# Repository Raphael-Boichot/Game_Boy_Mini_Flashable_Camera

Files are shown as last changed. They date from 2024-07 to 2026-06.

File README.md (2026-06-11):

# The Game Boy Mini Flashable Camera - a fork

**A license free flashable version of the Game Boy Camera, in a small form factor. A fork I've made to render the project doable without external help. All necessary informations are here. I also propose an alternative simpler design requiring less components.**

**The license (rather the absence of it) allows you to do what you want with your mod: selling it, offering service for doing the mod, modifying it starting from the schematic, it's up to you.**

**The design was made from scratch and people involved have no hidden conflict of interest with any other similar project. We are not here for money or fame, this project is just a gift to the Game Boy modding community.**

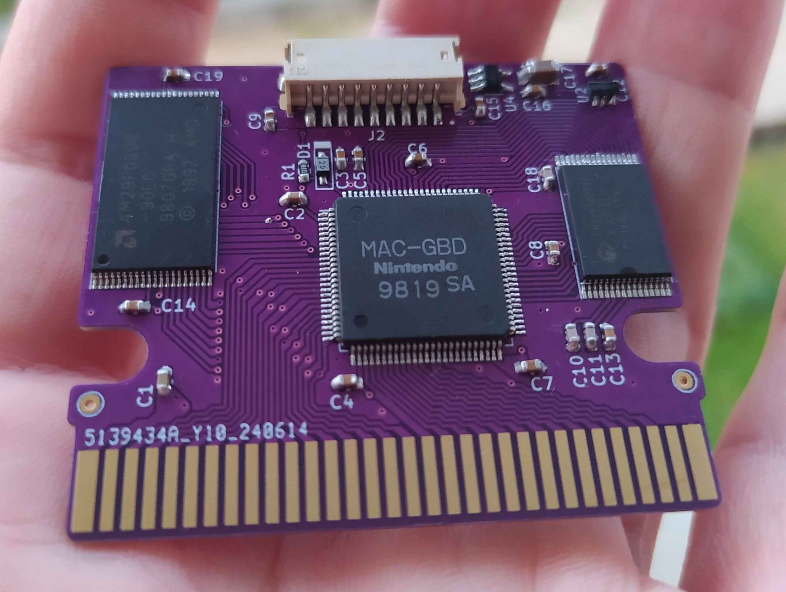
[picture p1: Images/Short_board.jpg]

**Isn't this gorgeous in purple ?** (Credit: Raphaël BOICHOT)

The current release has been produced, assembled, tested and bullet proofed. The board is compatible with any regular camera ROM (Game Boy Camera, Pocket Camera, Hello Kitty, Zelda special edition and [Debagame tester](https://tcrf.net/Proto:Game_Boy_Camera)) and homebrews like [Photo!](https://github.com/untoxa/gb-photo) or [2bit PXLR Studio](https://github.com/HerrZatacke/2bit-pxlr-studio). It is recommended to flash this board with a [GBxCart](https://www.gbxcart.com/) and [FlashGBX](https://github.com/lesserkuma/FlashGBX) as support is guaranteed. FlashGBX automatically recognizes it without doing anything. Other flashing devices (GB Operator, Cyclones and other Chinese oddities) were not tested, try them by yourself. Some considerations made in this repository are just related to me being a cheap modder living in Europe and everything else being sold from US/China, so adapt the reading level to your own localization / wealth.

***Note from April 2026: I do not (and won't) keep track of the main fork and its more or less documented updates as the version forked here (1.4) perfectly does the job. The 1.5 (dismissed since) was just the 1.4 with a pad to skip the signal inverter and the current 2.0 is a double bank PCB with added functions which does not have the beautiful simplicity of the 1.4.***

## Why this fork ? Isn't the main branch enough ?

In short: no. Let me explain the story first, it's interesting.

The main branch has been published by 2BitWizard with a minimalistic readme during the summer 2023. The author kindly shipped to me some pre-release boards for feedback (as well as to a bunch of other modders). 2BitWizard and I were both quite active members on some retro stuff related Discord. Unfortunately, 10 months passed before I found time/motivation to dive seriously into the project (I have no excuses, even though I've spent the year dealing with shit). Meanwhile, I lost any means to contact the author as well as the manual to assemble the pre-release boards (which were different enough from the current project to be lost in translation) after leaving progressively all social media for various good reasons.

But I still owed 2BitWizard a feedback. Because yes, I'm an old-fashioned guy with principles.

To my big surprise, the main branch stayed nearly inactive after the initial commits. Out of curiosity, I've decided to restart the mod from zero, alone with my workbench, putting aside my pre-release boards that I was unable to populate anymore. I wanted to confirm that it was possible to make the project with the only informations, gerbers and schematics provided in the main repository. I found inconsistencies. I had to seek for external help and needed cross validation (see the acknowledgements). I had to fix important things (confirmed by the original author since).

So.

I've decided to make my own fork. I like this project.

## What has been changed compared to the main branch ?

- Inconsistencies between BOM and schematic have been fixed, BOM is simplified;
- All 22 pF caps have been replaced with 39 pF to permanently fix [image artifacts](/Images/Artifacts_with_22pf_C10.png) linked to FRAM. The initial author also shifted to a higher value (33 pF) after observing the same artifacts;
- The project now contains all necessary information to be completed without having to cross-check datasheets and schematics and make educated guesses;
- An [alternative design](/Alternative_design) with less components and using the same PCB is also proposed.

## Minimal hardware/skill required in addition to all the BOM before starting anything

- A multimeter with at least a beeping continuity mode for troubleshooting;
- A 60W soldering iron with a fine tip and a real temperature control. Cheap pencil shape soldering irons are **NOT** an option to consider unless you want to kill yourself;
- A hot air gun (ideally a reflow station) or a heating plate to desolder the MAC-GBD;
- Good quality solder wire/flux or solder paste and solder wick;
- Isopropanol in large quantities to clean all the flux mess;
- A magnifying system like an USB microscope or binocular magnifiers;
- A GBxCart flasher and FlashGBX software. Other flashers may or may not work;
- Some kapton tape (or any whatever branded polyimide tape) to cover the PCB gold fingers during soldering;
- Fine tweezers to handle the tiny components (and experience the joy of capacitor tombstoning);
- 3 hours of free time with your preferred music in background and no kids whining around;
- A good skill in soldering because **this is not a beginner project**. It can really end as a mess if you don't know what you are doing. Keep in mind that the mod is not intended to be easily reversible.

## What to fit it with

The GB mini flashable camera comes in two PCB versions that fit any kind of cool existing shells. It is meant to be as versatile as possible. **The long PCB can be turned into a short PCB by simply breaking the PCB neck so I recommend ordering only the long one as it lets you more shell options.**

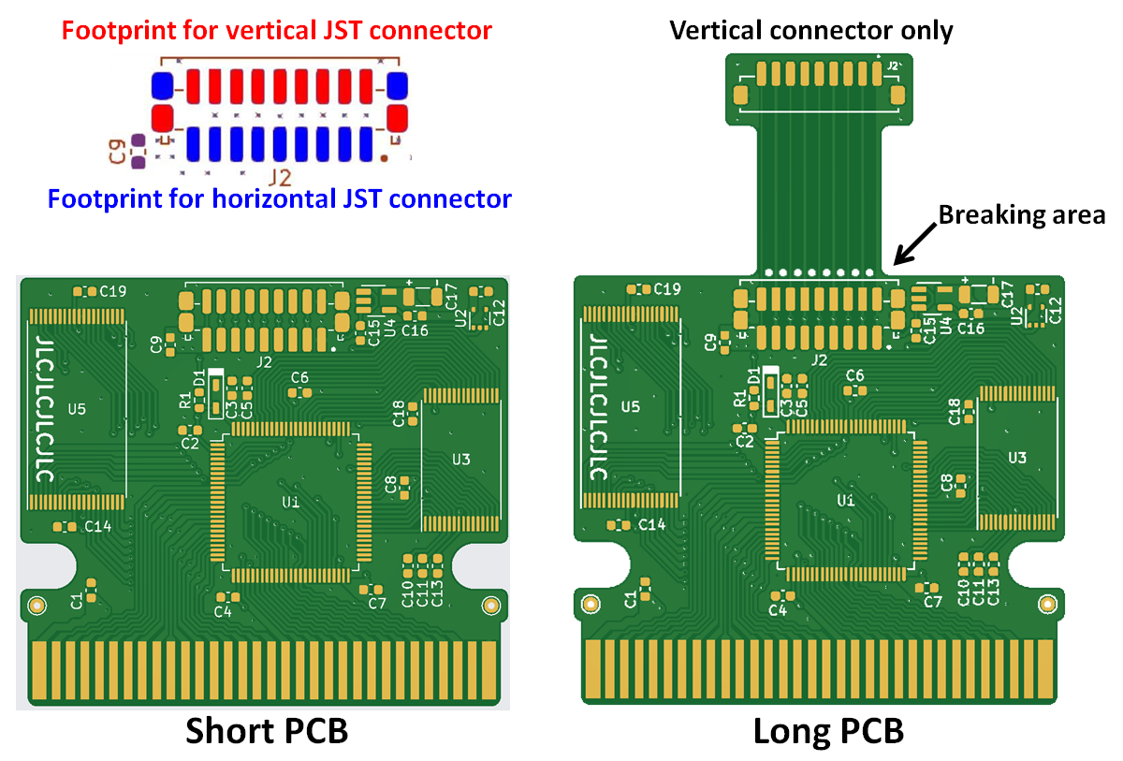
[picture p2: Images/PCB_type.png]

(Credit: Raphaël BOICHOT)

The GB mini flashable camera in short version fits perfectly with the [Camera+ Mini shell](https://ko-fi.com/s/a4d7bd649a). With this shell, you can reuse the regular camera sensor ribbon. **With the short PCB, use an horizontal JST connector as clearance is very low.**

## Showcase with the short PCB in a Camera+ Mini shell

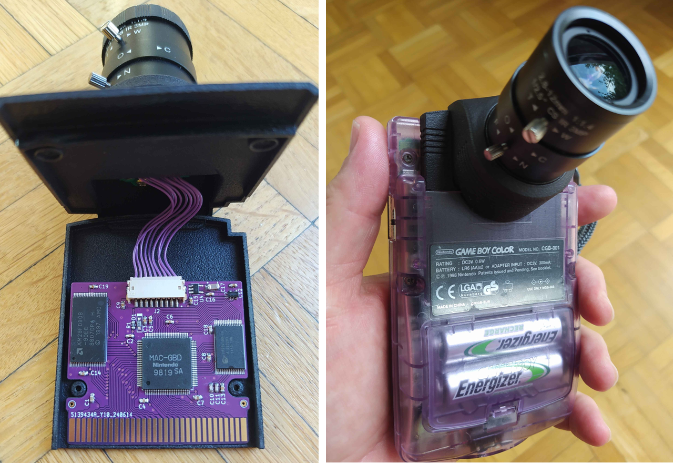
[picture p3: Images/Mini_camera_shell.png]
game boy camera flashable

(Credit: Raphaël BOICHOT)

The long PCB version has a "neck" that allows mounting it in a regular Game Boy Camera or a [Game Boy Camera+ shell](https://ko-fi.com/s/9457d1cc6e) with the regular sensor ribbon as well. **The long neck must be populated with a vertical JST connector only.**

## Showcase with the long PCB in a regular (but fancy) camera shell

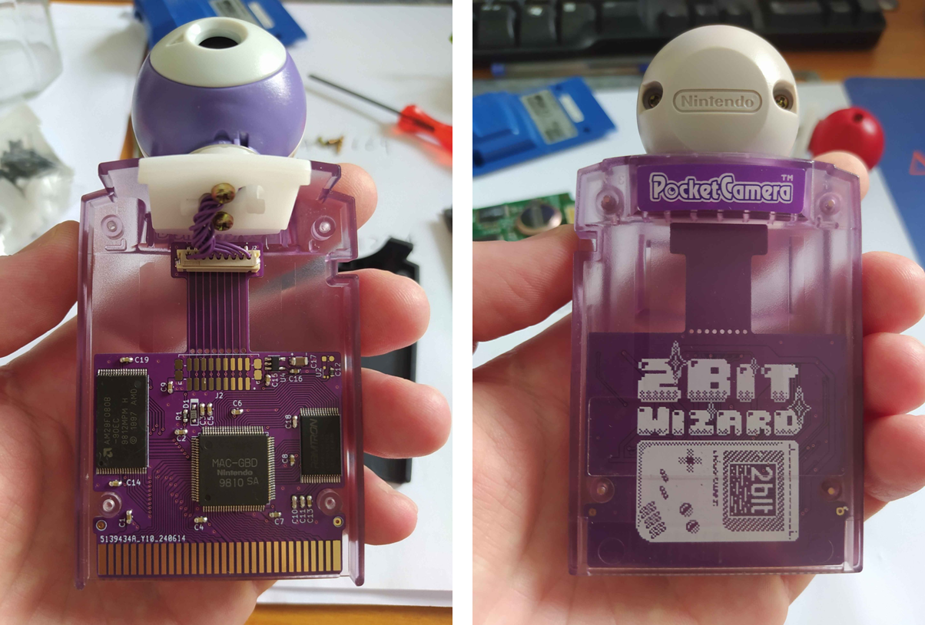
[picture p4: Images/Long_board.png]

Atomic purple case with purple PCB, what could go wrong ? (note the missing signal inverter on purpose, [this is why](/Alternative_design)). Credit: Raphaël BOICHOT.

In case you want to mount the **short PCB** in a regular camera shell (why not after all), you will need a **longer ribbon cable**, and that's where the pain begins. 
**Aliexpress JST cables are much too thick and stiff for that task** (plus they are just crap, do not buy them) and you must order a genuine JST cable. The only known supplier for genuine cables is Digikey (with prohibitive shipping fees to Europe). Choose a [type B cable "socket to socket" ](https://www.digikey.fr/en/products/base-product/jst-sales-america-inc/455/A09ZR09Z/588181). The regular camera cable is [2 inches long](https://www.digikey.fr/en/products/detail/jst-sales-america-inc/A09ZR09ZR28H51B/6708551), so take at least a [4 inches one](https://www.digikey.fr/en/products/detail/jst-sales-america-inc/A09ZR09ZR28H102B/9972202). Digikey ribbon cables are just a bit stiffer than the genuine cables but they can sustain the same amount of bending/torsion without losing connection, in brief they are damn good quality. Fun fact: the JST male connectors from Aliexpress, in the other hand, are just perfectly OK.

Please follow the [building instructions from the original author](/Building_guides/build.pdf) (also given in next section) for PCB ordering options. Use [JLCPCB](https://passport.jlcpcb.com/) for ordering if you live in Europe. They offer VAT compliant services for European customers and very cheap shipping options. I typically got 5 boards ENIG finish shipped to France for 23€ in 2024.

**IMPORTANT note:** you can harvest the voltage regulator from **some versions** of the Game Boy Camera. They are populated either by the U4 or U5 regulator. The current board is designed to work with either the regulator linked in the BOM or the U5 regulator harvested from the original camera cart. **U4 from the original board will not work.** If you're using a new 3V0 regulator from the BOM list, the **C16 capacitor will not be necessary.** Unlike the original 3V0 regulator, the pin connected to this capacitor is not connected on the new 3V0 regulator. **I recommend anyway buying the regulator indicated in the BOM to start from fresh.**

## Component location and orientation on PCB

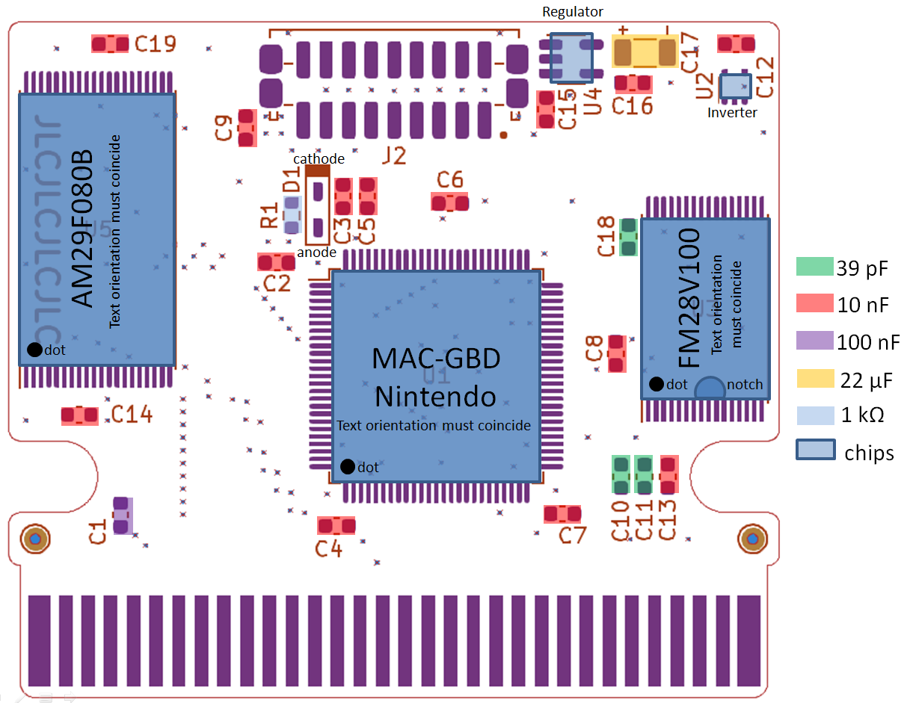
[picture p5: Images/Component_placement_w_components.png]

(Credit: Raphaël BOICHOT)

It's not an interactive BOM but it will do the job. If you are colorblind, please refer to the next table which is the same. **No component other than the MAC-GBD need to be harvested from the original camera PCB.** You can also take a look to my proposal of [alternative design using less components](/Alternative_design).

## Component list (BOM)

|Silkscreen |Value |# |Footprint |Exact reference |Aliexpress link |
|---|---|---|---|---|---|
|C1	|100nF	|1	|0603 |Capacitor Ceramic (X7R)	|[100 nf - 0603](https://www.aliexpress.com/item/1005005690927737.html)|
|C2 to C9, C12 to C16, C19	|10nF	|14	|0603 |	Capacitor Ceramic (X7R)|[10 nf - 0603](https://www.aliexpress.com/item/1005005690927737.html)|
|C10, C11, C18	|39pF	|3	|0603 |Capacitor Ceramic (X7R)|[39 pf - 0603](https://www.aliexpress.com/item/1005005690927737.html)|
|C17	|22µF	|1	|1206 |Capacitor Tantalum (≤10%)	|[22 µf, 16V X7R - 1206](https://www.aliexpress.com/item/1005006022131059.html)|
|D1	|N/A	|1	|SOD-123 |BAT54W-HG3-18 Schottky diode|[BAT54W - SOD-123](https://www.aliexpress.com/item/1005007021313163.html)|
|J2	|N/A	|1	|N/A	|JST ZH1.5mm (9 pins)	Camera Connector (male, horizontal or vertical)|[9 pins JST connectors](https://www.aliexpress.com/item/1005006028155508.html)|
|R1	|1kΩ	|1	|0603 |Resistor	|[1kOhm - 0603](https://www.aliexpress.com/item/1005005677654015.html)|
|U1	|N/A	|1	|TQFP-100 |MAC-GBD gamecart mapper chip|Harvest from cart|
|U2	|N/A	|1	|SC-88A-5 |M74VHC1GU04DFT1G Signal inverter|[M74VHC1GU04DFT1G](https://www.aliexpress.com/item/1005006984696269.html) - see notes before ordering|
|U3	|N/A	|1	|TSOP-I-32 |FM28V100-TG FRAM|[FM28V100-TG - TSOP-32](https://www.aliexpress.com/item/1005007221226758.html)|
|U4	|N/A	|1	|SOT-23-5	|NCP718ASN300T1G 3V0 voltage regulator|[NCP718ASN300T1G - SOT-23-5](https://www.aliexpress.com/item/1005005585077756.html)|
|U5	|N/A	|1	|TSOP-I-40 |AM29F080B	Flash memory|[AM29F080B - TSOP-40](https://www.aliexpress.com/item/1005007324498768.html)|

The PCB was designed on purpose with "big" surface mount components only. Anything smaller than the 0603 footprint would be just sadistic for this kind of leisure project.
You can report dead Aliexpress links in the **issues**, I will update them ASAP. I did not try to optimize shipping fees here, there is maybe a cheaper combination of sellers.

## Schematic

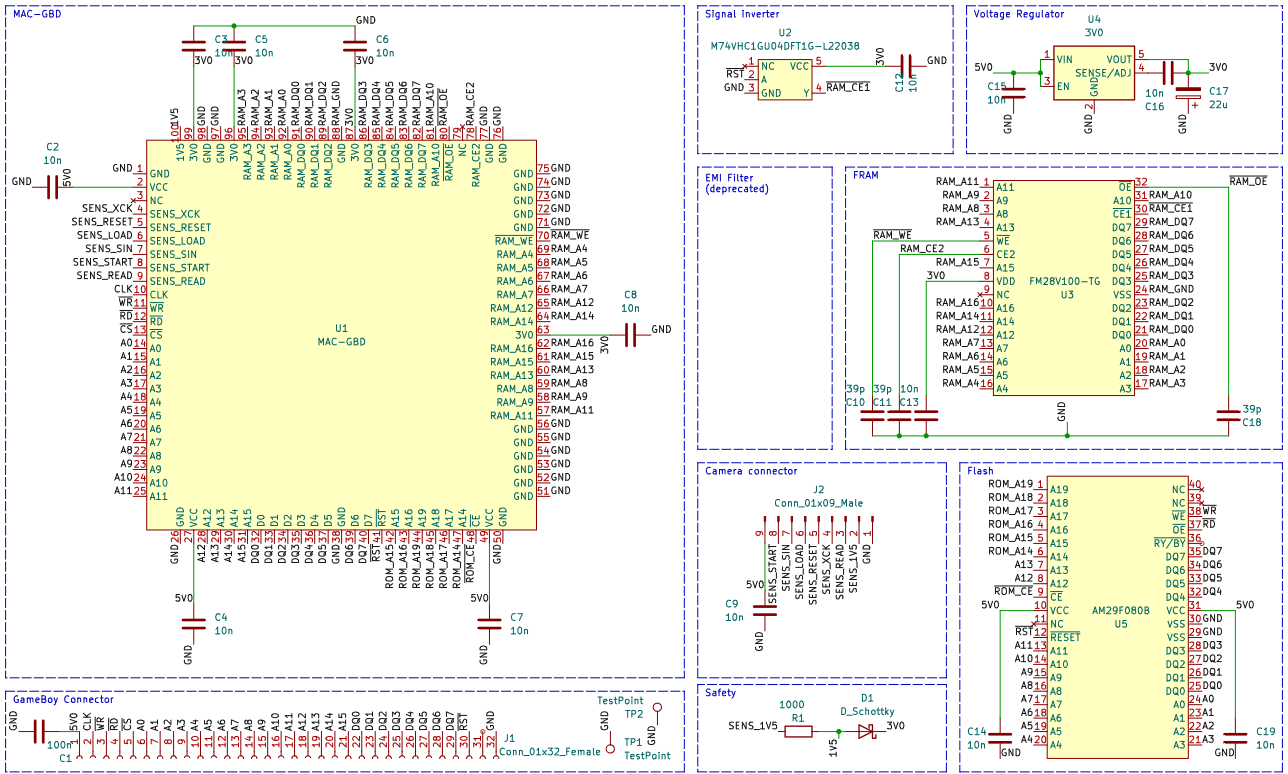
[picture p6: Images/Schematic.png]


## Overview of JLCPCB ordering options

Base Material **FR-4**, Layers **2**, Dimensions **Auto-filled**, PCB Qty **As desired**, Product type **Industrial/Consumer electronics**, Different Design **1**, Delivery format **Single PCB**,  PCB thickness **0.8**, PCB Color **As desired**, Silkscreen **As desired**, Surface Finish **ENIG**, Outer Copper weight **1 oz**, Via Covering **Tented**, Board Outline Tolerance **±0.2mm(Regular)**, Confirm Production file **No**, Remove Order Number **Specify a location**, Flying Probe Test **Fully Test**, Gold Fingers **Yes**, 30°finger chamfered **No**, Castellated Holes **No**.

## Notes (please read completely before attempting the project)

- The M74VHC1GU04DFT1G signal inverter, in particular in SC-88A package, can be tricky to source (only remaining seller is Mouser), so a solution is to switch to a MC74VHC1GU04DF1G (solution proposed by Digikey) or to another close package (like the SC−74A, only one you will receive from Aliexpress, whatever claim the sellers). **The SC-88A package is equivalent to SOT-353 or SC-70-5 if you search for old new stocks. The package SC−74A, slightly bigger, can be used too in case of no other choice, it barely fits, but fits anyway, on the SC-88A footprint (same pinout).** If it is not soldered correctly (cold joint), you will get a white image, easy to debug so. Do not hesitate to carefully bend the pins to ease the matching.
- The schematic only is **open source** and can be edited with Kicad. The author chose to not disclose the PCB layout whatever the reason. You have to create your own if you want to change something.
- C10, C11 and C18 capacity has been increased compared to the original design to remove any graphical glitch due to FRAM timing inconsistencies. It is now perfectly working with the cap values proposed in this fork (39 pf versus 22 pf originally).
- The AM29F080B, as most of 5 volts flash chips, is discontinued since many years but easy to find on Aliexpress for cheap (batches are mainly recycled chips). It can be fun to dump the content before flashing it to see what the chip usage was before its recycling (it is said that some old phone flash chips can be funny to dump).
- Some late versions of the FM28V100 FRAM by Cypress Semiconductors come without a dot to indicate pin 1 but only a side notch. The side notch also indicates the row where pin 1 is located, so it must be soldered with notch pointing down (same as the dot if present).
- Recycled FRAM from Aliexpress are 10x cheaper than new ones sold on Mouser or Digikey. The FM28V100 is known for being very reliable in general. I never got any defective FRAM chip of this capacity from Aliexpress. Seeing the price, it's a no-brainer for me: recycled chips only. Sidenote: RAMTRON was acquired by Cypress semiconductors in 2014, both are the same fabless manufacturer now. There is no rational reason to prefer RAMTRON over Cypress branded chips. RAMTRON branded chips are just older stocks.
- The low voltage Schottky diode proposed here is generic and any equivalent one will do the job (there are several). The original camera used a Panasonic MA784 with marking **2D** (discontinued), among other undocumented variations, you can take inspiration from its datasheet. The RB510VM-30 is a possible alternative for example. It must have the **lowest possible forward voltage drop and the highest possible reverse voltage**. Its purpose is to protect the 0-3.3V MAC-GBD internal analog to digital converter from any overvoltage coming from sensor image signal, so the anode is connected to VOUT (1V5 in the schematic) and the cathode to 3V0. It triggers at around 3.18V on the anode. Whatever the diode used, it has a specific mark on the cathode (see corresponding datasheet, can be a white line on black background or the inverse). Compared to the main branch, I've removed the BAT 63-02V as possible alternative to the Schottky diode due to its very low reverse voltage (3V only versus 30V for the original diode).
- Most parts can be found on Aliexpress, Mouser and Digikey except for the ribbon cable (Digikey only). I overall recommend ordering on **Aliexpress or Mouser** if you are in Europe, after a very deceptive customer experience with Digikey, to say the least.
- You can easily desolder the MAC-GBD by using a hot air gun (set at about 400°C) on the **back side** of the original board until the chip falls by itself or after a gentle shaking (add flux to ease the melting). This is by far the most simple way I've found (I do not own a heating plate). I do not recommend using low temp solder or other bismuth containing crap. No need. The author of the original project recommends using a heating plate set at 250°C. In any case, work fast to minimize at most heat budget on the chip.
- Lead free solder in wire can be very crap depending on the alloy and could be a pain to melt due to high melting point, in particular without flux core. Either use old good lead/tin alloy with flux core (and a ton of flux anyway) if you can find some, or quality lead free solder paste. And always remind the rule of thumb when using flux: "the bigger the blob, the better the job".
- The ferrite beads filters have been removed from the definitive PCB even if they are still mentioned in the pdf description of the project.
- The schematic is **clear and comprehensive enough to troubleshoot any issue** by yourself with a multimeter in continuity mode. Easy check after soldering: the caps must **never** be shorted, two adjacent pins of the FRAM and flash memory must never be shorted (beware, it's not as simple on the MAC-GBD side). After that, any remaining issue is a just a matter of flow and reflow due to some dry solder joint.
- It's **very recommended** to use a magnifying system (USB microscope or binocular magnifier). Soldering with bare eyes is possible if you are lucky enough to get the device working first try but any issue will be impossible to troubleshoot.
- The PCB ENIG finish can be hard to "wet" with solder depending on the flux used. I used a generic "no clean" flux in a syringe, which was OK in my case (good flux wetting, easy to "no clean" with isopropanol, not greasy and no headache after long soldering sessions contrary to some other el cheapo Aliexpress fluxes in metal containers I used to spread before). AMTECH seems to be a good brand if you need to choose one.
- Of course, cover the cartridge connector completely with kapton tape during soldering to avoid any solder splats on them. They are basically **impossible** to remove after, so better avoid them.
- I also recommend to clean with flux/solder wick/isopropanol and unbend very thoroughly under microscope the pins of the MAC-GBD or any recycled chip **before** soldering them to the PCB. A solder bridge due to a metal particle between/below pins (like a tiny ripped pad, own experience...) is very annoying to remove (you basically have to remove the whole chip to get rid of it and clean all the pins, so better doing it before becoming crazy).
- I've soldered the components in this order: chips (to have clearance), caps/diode/resistor, regulator/inverter, and then the connector. I've cleaned board between each step with isopropanol to get a clear view of the work and check for dry solder joints and obvious shorts.
- First connection to FlashGBX will always report a bad/unknown mapper/ROM but as soon as you try to flash a ROM everything will go fine. I recommend flashing a regular ROM first (which fills the whole 1MB flash chip) and fill the whole memory with different images for testing. If after reboot all your images are still there without artifacts, you're good to go with your new device !
- As the populated PCB is full "solid state", it can be cleaned by directly soaking it in isopropanol / hot soapy water and using a toothbrush, the caps risk nothing.
- I learnt soldering surface mount stuff years ago by just watching Youtube and praticing, so it's not rocket science either. Hardware is the key: choose powerful enough soldering iron with temperature control (typically an iron with power transformer and head in two different pieces, not single cord pen form factor with a knob, they are all crap), good solder alloy, good soldering wick, flux in a syringe, accurate magnifying device. Best is of course to start practicing soldering/desoldering with simplier projects first.
- I guess that the PCB can be fully assembled at once with solder paste and a heating plate/reflow station. I just have no experience doing this and you probably would have to prepare a stencil for that.

## Example of pictures taken with the Camera+ Mini shell and a 2.8-12 mm CS lens

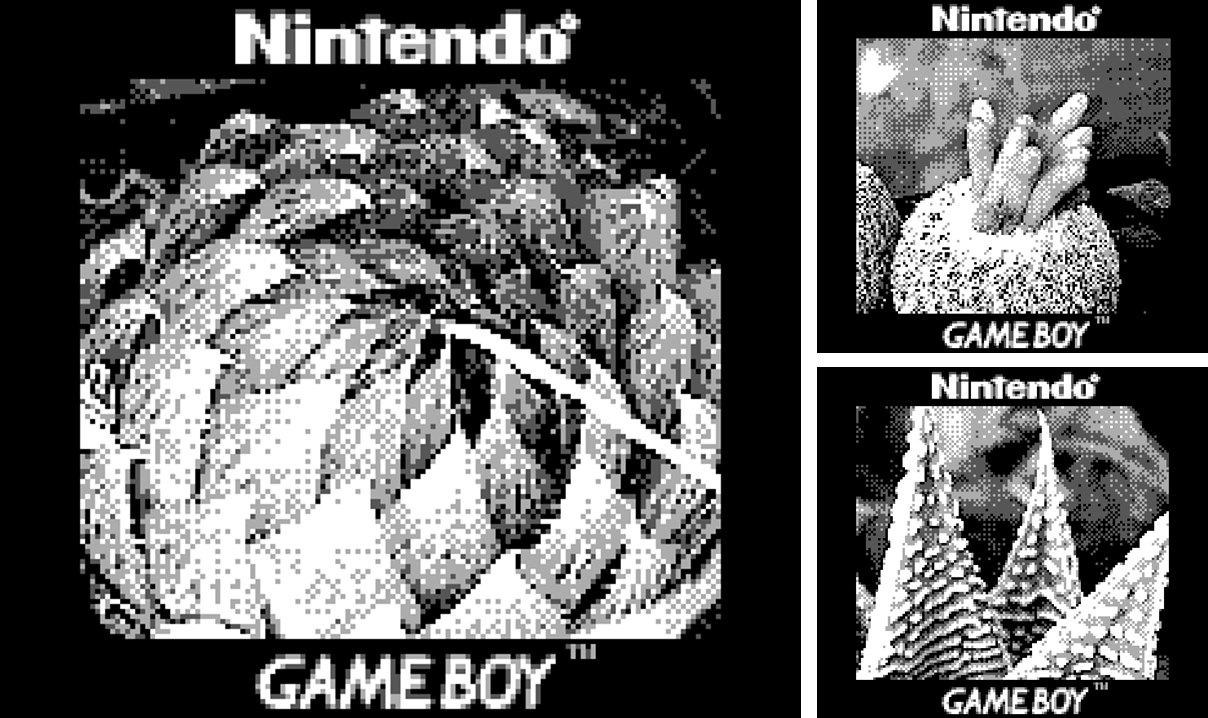
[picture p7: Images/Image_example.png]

(Credit: Raphaël BOICHOT)

## Notes for ordering the Camera+ Mini shell

- I've ordered [this version of the Camera+ Mini shell](/Shell) at JLCPCB with the following option: 3D Technology: MJF(Nylon) Material: PA12-HP Nylon Colors: Black Surface Finish: Dyeing-Dyed Black. It came very nice and sturdy like this. The price in 2024, shipped to France, was 17€ for the full set of pieces.
- The C/CS mount I bought was way to large to enter the front hole so I had to file its external diameter until it fit with a moderate force. At this step, you can adjust the C/CS mount deepness until your lens can easily focus to infinity before glueing it definitely by the inside. The mod is very well made so even with the C/CS ring completely pressed inside the hole, it must be OK.
- CS lenses are very cheap and good quality on Aliexpress. My go-to lens is a [2.8-12 mm](https://a.aliexpress.com/_EQWPAAN) which covers 99% of my needs. The 5-50 mm is not bad either. To guide your choice, the sensor crop factor is about 10 (5 mm with Game Boy Camera sensor is equivalent to 50 mm with full frame sensor). The original camera plastic lens is about 35 mm equivalent (3.5 mm with the sensor) to give a reference.
- The mod does reuse only screws from the genuine camera shell, which is clever ! You just need some 5 minutes epoxy for gluing the C/CS mount and nothing else.
- The mod is **fully reversible.**
- If you hesitate between the Camera+ and the Camera+ Mini shell, take the Camera+ Mini. It holds very firmly in place with heavy lens mods compared to the Camera+ which center of gravity is a little bit too high for my own taste.

## Notes while troubleshooting / trying new options

- I've received the signal inverter in the wrong package from two different Aliexpress sellers (package SC−74A, it was referenced as SC-88A but it was not). It barely fits and was tricky to solder correctly on the traces but it works. As long as the chip marking begins by V6, chip/pinout is the same. Lack of connection between FRAM and the signal inverter will result in a permanent white image, easy to recognize. I've tried to get rid of it by "shorting" RAM_CE1 to GND with a 1kOhms resistor (it has just the required length and makes a solid bridge, right pads on U2 foorprint), it of course also works.
- I've used an old new stock Panasonic MA784 Schottky diode because I bought a bunch of them years ago to confirm that the Game Boy Camera uses exactly the same.
- Using a 22 pf capacitor for C10 as recommended in the original repo led to image glitches on my side (I must point out that I did not specifically order X7R caps but was working at "room temperature" with unbranded caps). Typical image glitches due to weak caps with FRAM are missing brightness levels, more or less obvious (an [example can be seen here](/Images/Artifacts_with_22pf_C10.png)). As I knew that this very particular cap was crucial for FRAM stability (because I'm not a six-week-old rabbit either), I've tried doubling or dividing the value by two (and swapping the FRAM chip, I thought it was maybe the culprit but in fact not). Dividing the capacitance by two made glitches worse (image turned to 1 BPP). Doubling to 44 pf with two 22 pf in parallel completely fixes the graphical glitches. So I then tried a 39 pf cap to be closer from initial value and it was OK. As C11 and C18 are less critical than C10 and to avoid ordering too many different cap references, they were also increased to 39 pf. These values are validated as perfectly working on my side (on a 4-40°C temperature range at least). I think that 22 pf was a very minimal value with no safety/tolerance on design margin.
- I've soldered C16 in place even if it is not required as I used a new voltage regulator (I'm quite superstitious when dealing with electronics and there is never too much caps).

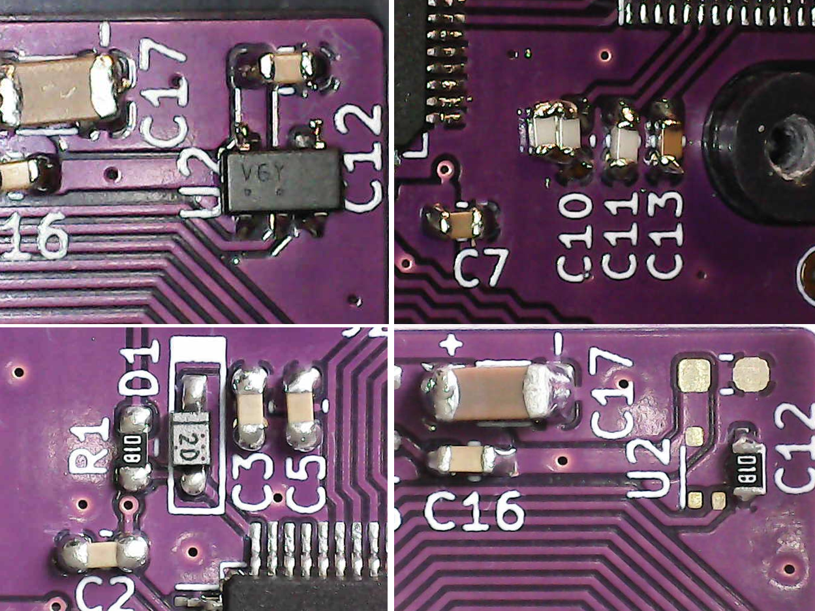
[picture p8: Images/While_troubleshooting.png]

(Credit: Raphaël BOICHOT)

## Some basic glitches easy to spot

Some cold solder joints between the MAC-GBD and the SRAM allow the camera to boot and create very predictible glitches. Just look at the image and you know where to reflow !

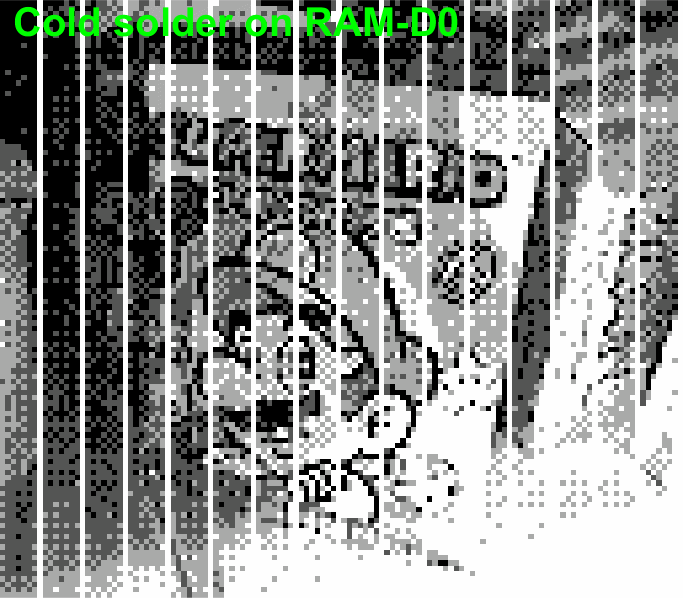
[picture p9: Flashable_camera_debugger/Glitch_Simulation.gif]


## Acknowledgements

- [Andreas Hahn](https://github.com/HerrZatacke) and [Mraulio](https://github.com/Mraulio) for helping me to complete this fork by confirming me some educated guesses I had to do and giving me some informations only accessible from the deep web.
- [2BitWizard](https://github.com/2BitWizard), original author, for bringing the project to fruition, sending me prototype boards and giving feedback on my feedbacks (Well, it wasn't exactly a thank-you either). 

- [2BitToy](https://ko-fi.com/2bittoy/) for his great/neat camera mods. Don't forget [donation](https://ko-fi.com/s/a4d7bd649a) if you appreciate this mod.

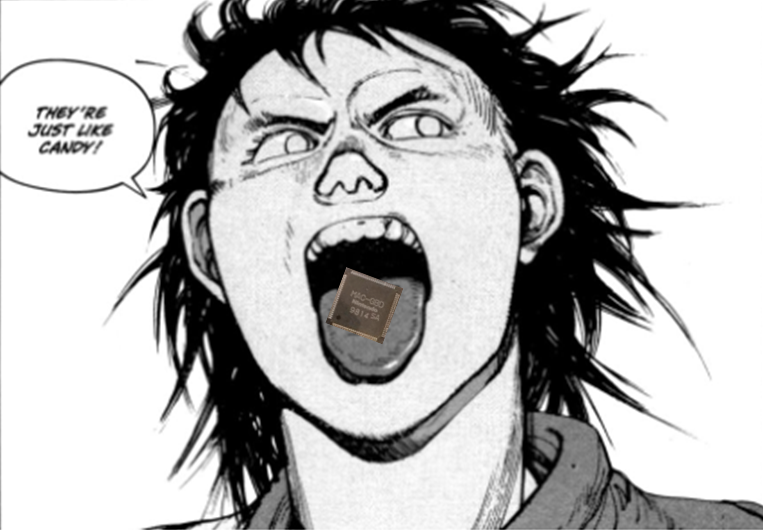
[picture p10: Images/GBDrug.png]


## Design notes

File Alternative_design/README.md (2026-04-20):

# Alternative design proposal for the 2BitWizard project

## 1. Get rid of the signal inverter

RAM_CE1 can be connected to ground directly, without the signal inverter. You can use a 1kOhms resistor to make the bridge as it is exactly the good lenght, just be carefull to not short RST and GND in the process. You can get rid of C12 in this case (see [an example here](/Images/While_troubleshooting.png)). My understanding is that the RESET signal is intended to be pulled down by the [battery backup management system](https://github.com/MouseBiteLabs/Game-Boy-MBC3-Cartridge/tree/main/Technical) (not used here because FRAM), to halt **both CPU operation AND writing to SRAM** when voltage is unstable while the Game Boy is powered down. But as it is pulled high on the Game Boy CPU side by default, the signal inverter pulls it down and always allows writing to the FRAM when Game Boy is ON. What a wire to ground does perfectly too. I can find at least as many arguments pro or against grounding RAM_CE1 or using the inverter.

**Possible placements for a 1kOhms resistor (or jumper wire, or 0 Ohm) to ground RAM_CE1 pin**
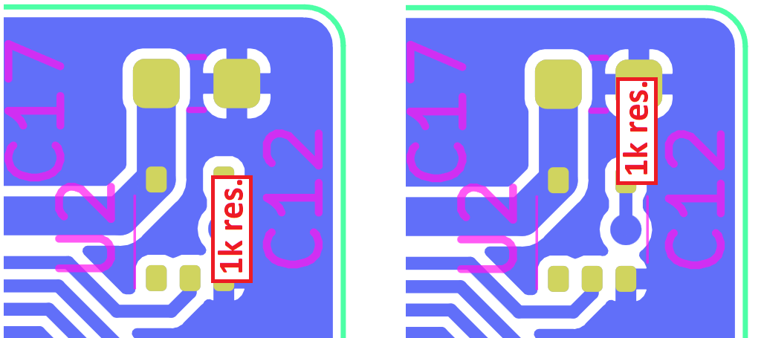
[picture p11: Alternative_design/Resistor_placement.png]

(Credit: Raphaël BOICHOT)

The author has since released a ~~1.5~~ 2.0 version (see [original repo](https://github.com/2BitWizard/GB_Mini_Camera)) that just adds a jumper (JP1) to do this cleanly. I however did not test this release.

## 2. Use only 100 nf caps on the voltage lines

Use only 100 nf capacitors instead of 10 nf capacitors on voltage lines to reduce the number of references to buy. 100 nf or more is the default cap value for many cart mods on voltage lines, so do not hesitate as 10 pf caps are of no use for other related mods. 

**Alternative capacitor placement on PCB**
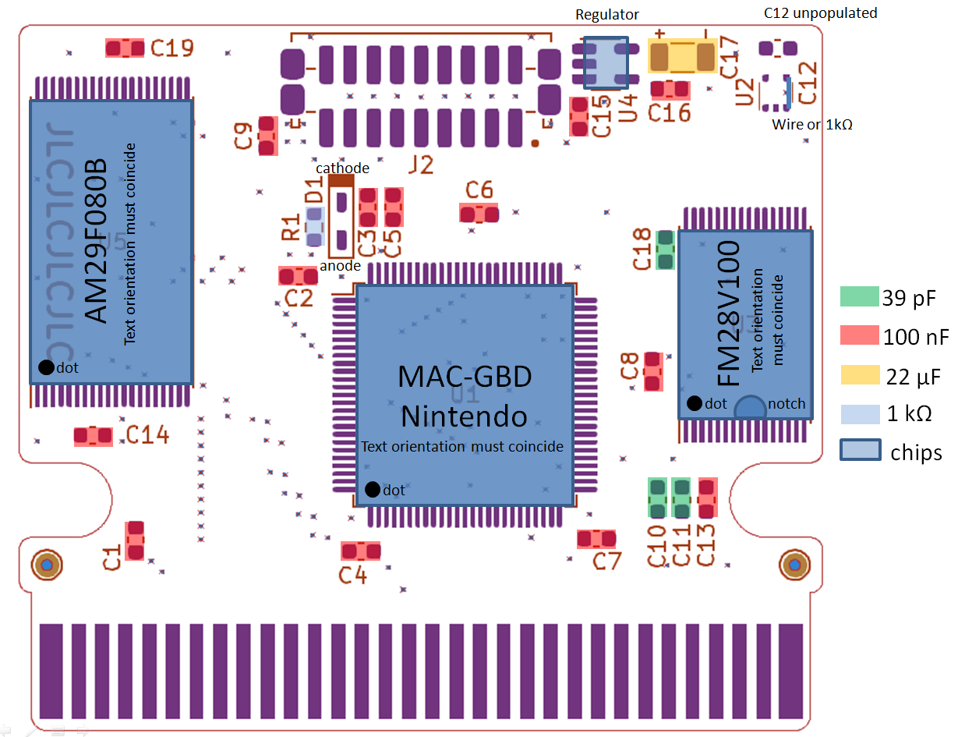
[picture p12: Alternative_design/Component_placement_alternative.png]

(Credit: Raphaël BOICHOT)

**Alternative schematic**
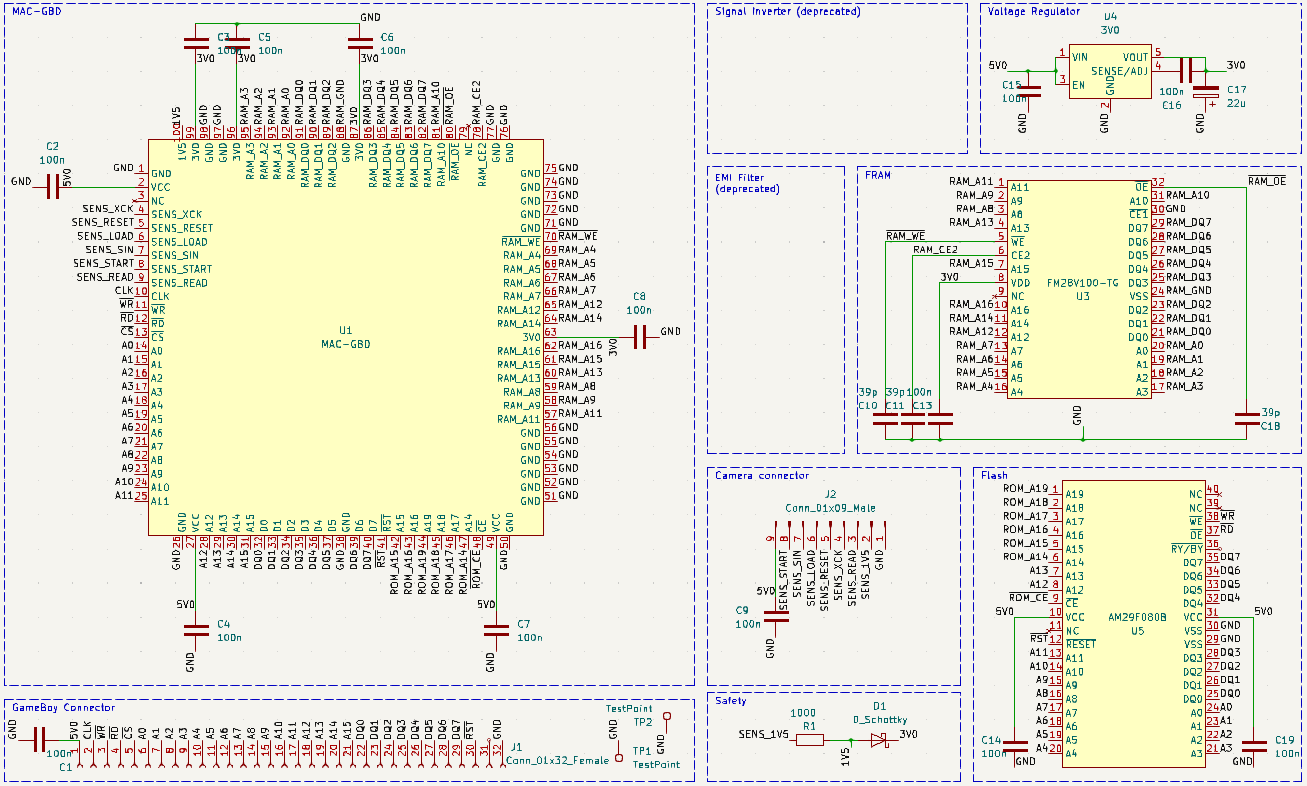
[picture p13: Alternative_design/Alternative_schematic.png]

(Credit: Raphaël BOICHOT)

## Alternative BOM

|Silkscreen |Value |# |Footprint |Exact reference |Aliexpress link |
|---|---|---|---|---|---|
|C1 to C9, C12 to C16, C19	|100nF	|15	|0603 |	Capacitor Ceramic (X7R)|[100 nf - 0603](https://www.aliexpress.com/item/1005005690927737.html)|
|C10, C11, C18	|39pF	|3	|0603 |Capacitor Ceramic (X7R)|[39 pf - 0603](https://www.aliexpress.com/item/1005005690927737.html)|
|C17	|22µF	|1	|1206 |Capacitor Tantalum (≤10%)	|[22 µf, 16V X7R - 1206](https://www.aliexpress.com/item/1005006022131059.html)|
|D1	|N/A	|1	|SOD-123 |BAT54W-HG3-18 Schottky diode|[BAT54W - SOD-123](https://www.aliexpress.com/item/1005007021313163.html)|
|J2	|N/A	|1	|N/A	|JST ZH1.5mm (9 pins)	Camera Connector (male, horizontal or vertical)|[9 pins JST connectors](https://www.aliexpress.com/item/1005006028155508.html)|
|R1	|1kΩ	|2	|0603 |Resistor	|[1kOhm - 0603](https://fr.aliexpress.com/item/1005005677654015.html)|
|U1	|N/A	|1	|TQFP-100 |MAC-GBD gamecart mapper chip|Harvest from cart|
|U3	|N/A	|1	|TSOP-I-32 |FM28V100-TG FRAM|[FM28V100-TG - TSOP-32](https://www.aliexpress.com/item/1005007221226758.html)|
|U4	|N/A	|1	|SOT-23-5	|NCP718ASN300T1G 3V0 voltage regulator|[NCP718ASN300T1G - SOT-23-5](https://www.aliexpress.com/item/1005005585077756.html)|
|U5	|N/A	|1	|TSOP-I-40 |AM29F080B	Flash memory|[AM29F080B - TSOP-40](https://www.aliexpress.com/item/1005007324498768.html)|

**These modifications were bullet-proofed in any situation I can test, and I have lots of imagination (repeated hard and soft resets, custom and regular roms, combined with DMG, modded DMG, GBC, modded GBC, GB Boy Colour and GBA).** You can cumulate these two mofifications or use them separately, it works too (i.e. 100 nf caps with inverter or 10 nf caps without inverter). Enjoy !

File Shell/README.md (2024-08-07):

The GB camera mini shell is given here for convenience but you are strongly advised to look at the donation link from the [Camera+ Mini shell author](https://ko-fi.com/s/a4d7bd649a).

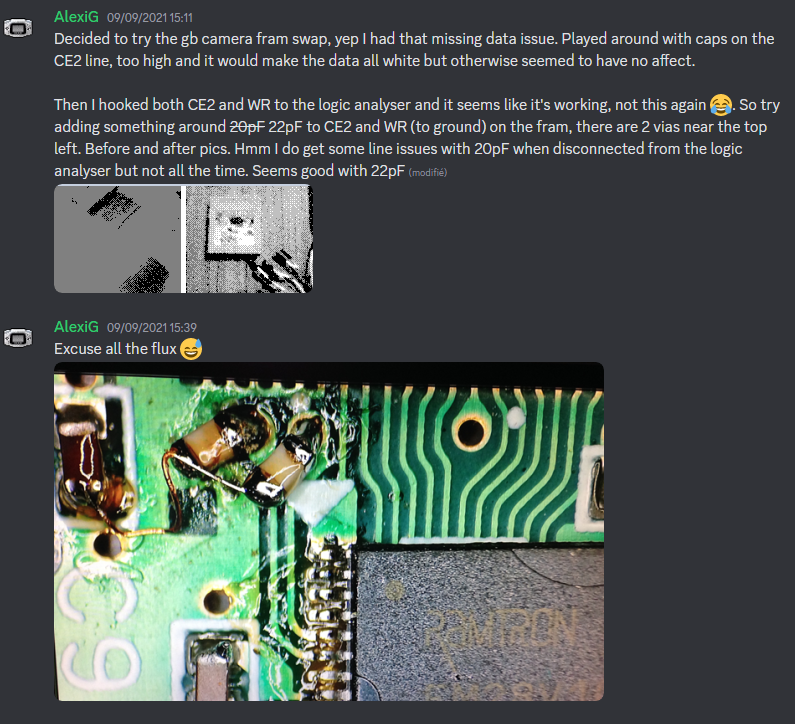
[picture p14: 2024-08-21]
Images/22pf_cap_story.png

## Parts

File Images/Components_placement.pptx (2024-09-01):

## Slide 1

Footprint for vertical JST connector

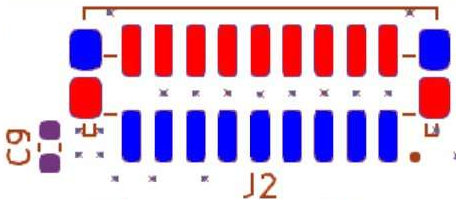
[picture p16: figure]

Footprint for horizontal JST connector

Vertical connector only

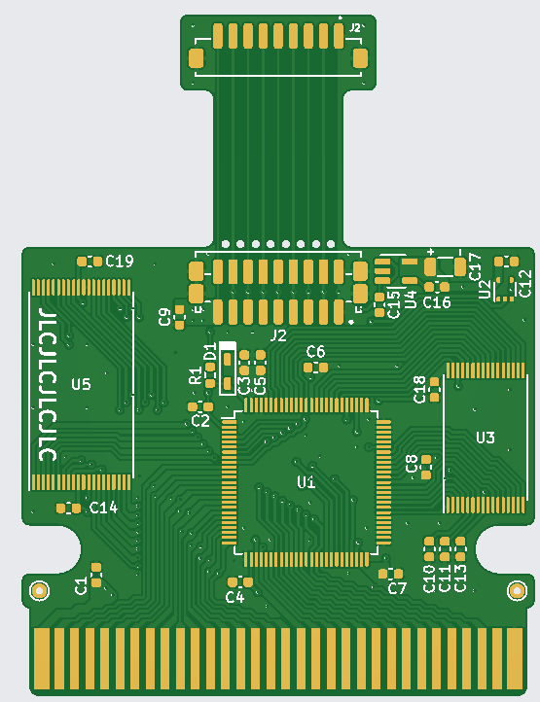
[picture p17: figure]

Long PCB

Breaking area

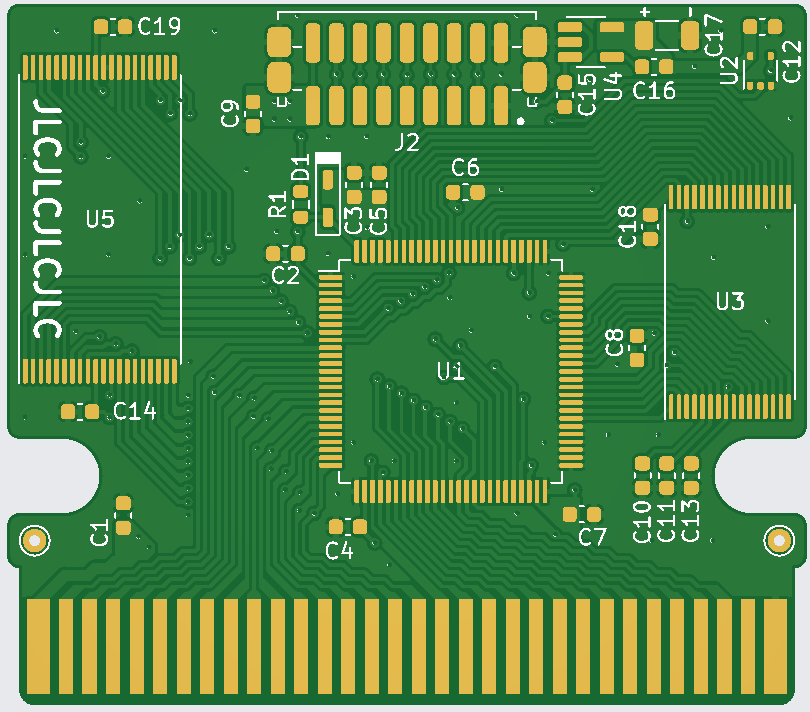
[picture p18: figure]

Short PCB

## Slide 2

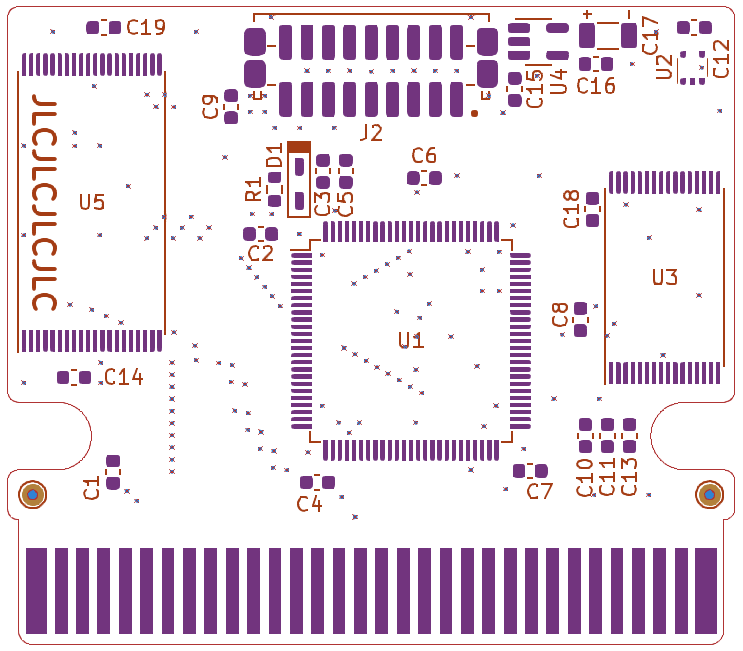
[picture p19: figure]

Regulator

AM29F080B

Text orientation must coincide

Inverter

cathode

FM28V100

Text orientation must coincide

anode

MAC-GBD
Nintendo

Text orientation must coincide

39 pF

10 nF

dot

100 nF

dot

notch

22 µF

1 kΩ

dot

chips

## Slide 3

Regulator

C12 unpopulated

AM29F080B

Text orientation must coincide

Wire or 1kΩ

cathode

FM28V100

Text orientation must coincide

anode

MAC-GBD
Nintendo

Text orientation must coincide

39 pF

dot

100 nF

22 µF

dot

notch

1 kΩ

chips

dot

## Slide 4

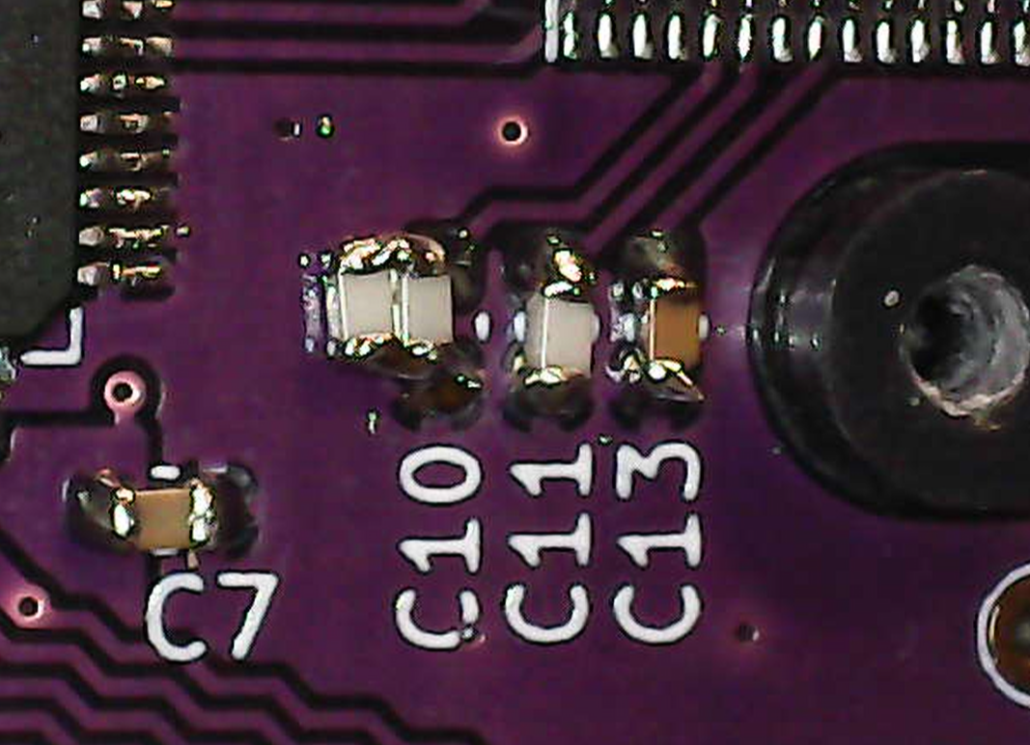
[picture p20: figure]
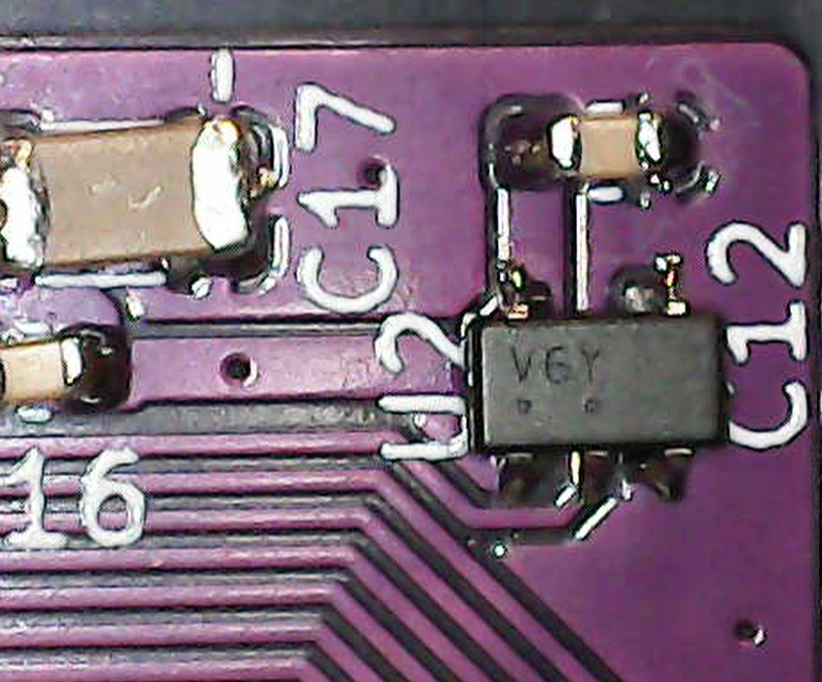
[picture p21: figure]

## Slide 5

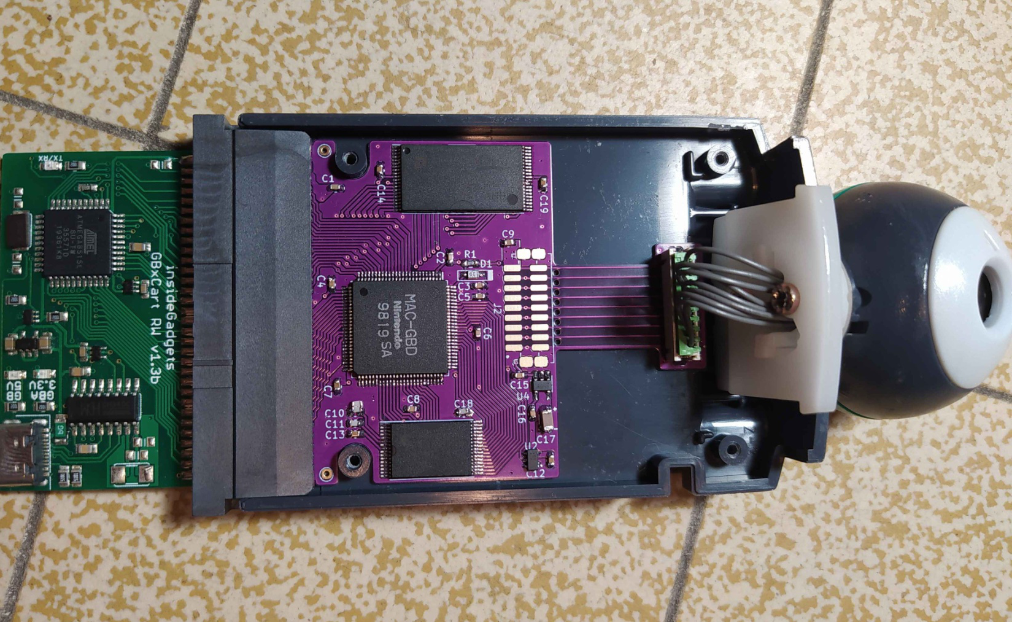
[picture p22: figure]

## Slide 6

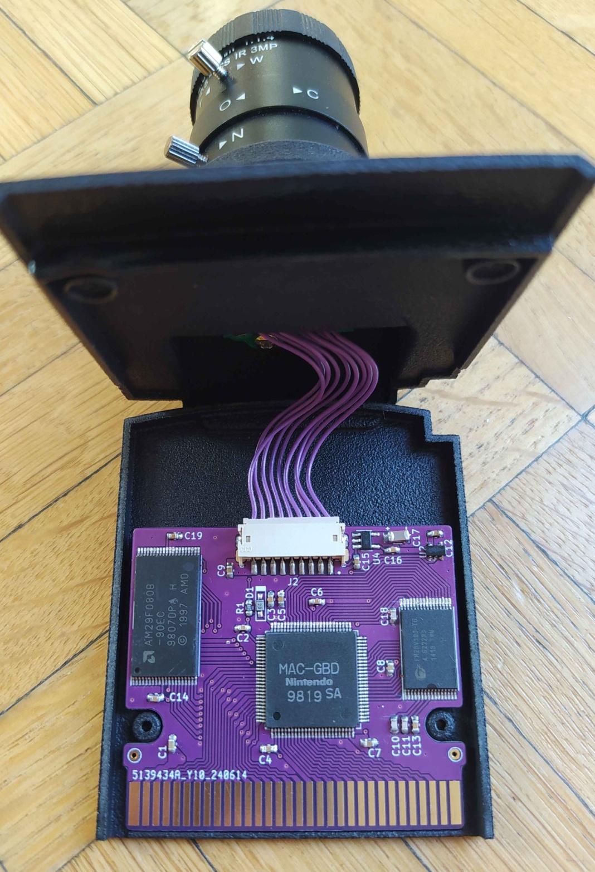
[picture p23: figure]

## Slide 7


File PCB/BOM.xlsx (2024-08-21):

Value | Count | References | Footprint | Name | Description | Alternatives
100 nF | 1 | C1 | 0603 (imperial) | Capacitor Ceramic (X7R) | Decoupling Capacitor
10 nF | 14 | C2, C3, C4, C5, C6, C7, C8, C9, C12, C13, C14, C15, C16, C19 | 0603 (imperial) | Capacitor Ceramic (X7R) | Decoupling Capacitor
39 pf | 3 | C10, C11, C18 | 0603 (imperial) | Capacitor Ceramic (X7R) | Decoupling Capacitor
22 uF | 1 | C17 | 1206 (imperial) | Capacitor Tantalum (?10%) | Filtering Capacitor
N/A | 1 | D1 | SOD-123 | BAT54W-HG3-18 | Schottky diode | RB510VM-30, MA784
N/A | 1 | J2 | N/A | JST ZH1.5mm (9 pins) | Camera Connector (male)
1 kOhm | 1 | R1 | 0603 (imperial) | Resistor | Resistor
N/A | 1 | U1 | TQFP-100 (14x14mm) | MAC-GBD from original cart | Main gamecart mapper chip
N/A | 1 | U2 | SC-88A-5 | M74VHC1GU04DFT1G-L22038 | Signal inverter | M74VHC1GU04DF1G
N/A | 1 | U3 | TSOP-I-32 (12.4x8mm) | FM28V100-TG | FRAM
N/A | 1 | U4 | SOT-23-5 | NCP718ASN300T1G | 3V0 voltage regulator
N/A | 1 | U5 | TSOP-I-40 (18.4x10mm) | AM29F080B | Flash memory

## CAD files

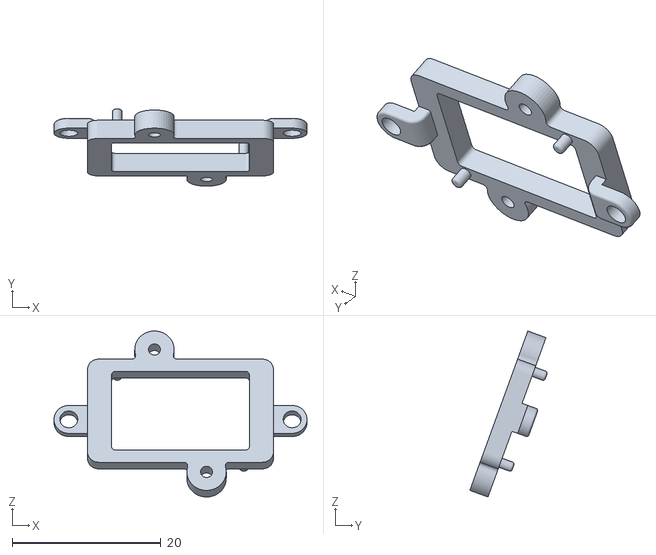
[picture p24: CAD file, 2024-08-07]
Shell/Camera_miniV2_SensorBracket.stl
34.0 x 10.4 x 22.3

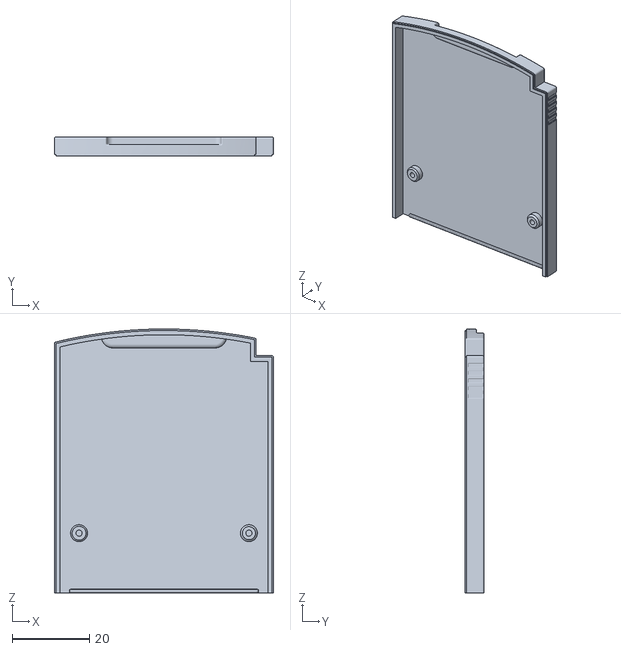
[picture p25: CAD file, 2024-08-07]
Shell/Camera_miniV2_ShellFront.stl
56.8 x 5.00 x 68.4

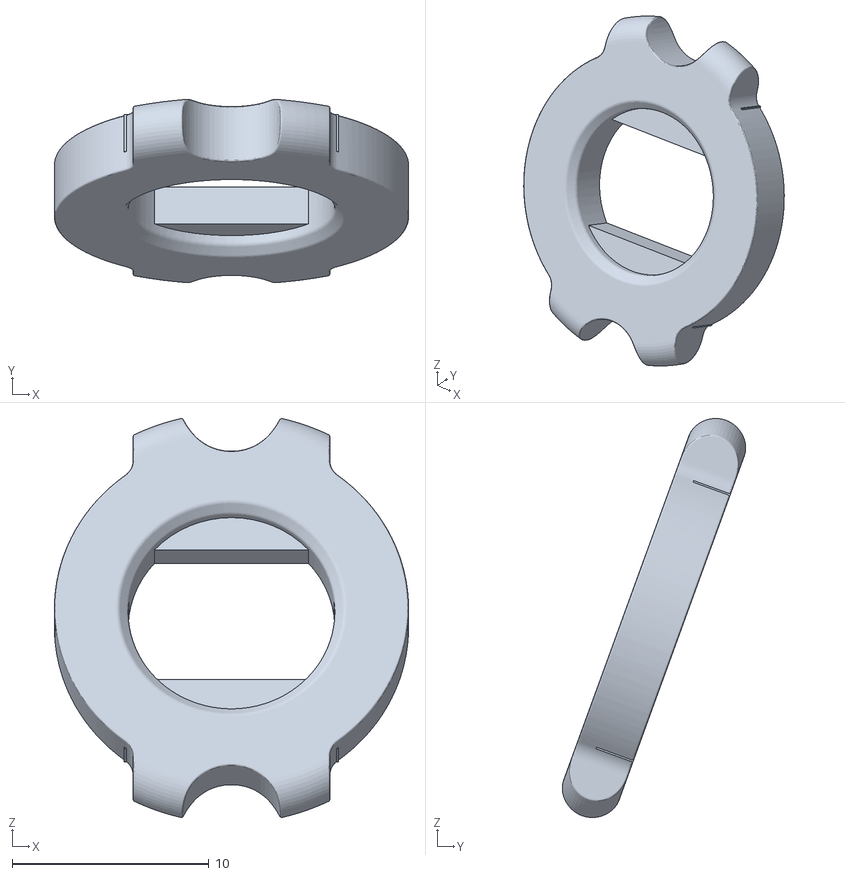
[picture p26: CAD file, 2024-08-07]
Shell/Camera_miniV2_FilterBracket.stl
18.0 x 9.32 x 20.3

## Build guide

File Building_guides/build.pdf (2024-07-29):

### GAMEBOY CAMERA CLUB

A BUILD GUIDE BY 2BITWIZARD

# Build Guide

August 25, 2023
Version I.

### Contents

1 Introduction | 2
2 Ordering the PCB | 2
3 Ordering Parts | 2
4 Assembling the PCB | 3
5 Troubleshooting | 4

### 1 Introduction

This document will cover the build process of the 2BitWizard flashcart. It will go over part selection, the ordering process and the actual build process. This document should only be used as a guideline, common sense will still be necessary to successfully complete this project. Following this guide will also not guarantee that your flashcart will work, user error, defect parts and other potential problems may still arise.

### 2 Ordering the PCB

There are a plethora of sites available to order PCBs from, the 2BitWizard flashcart however is designed with JLCPCB in mind. It complies with the tolerances of JLCPCB’s manufacturing process and also contains a line of placeholder text below the flash chip, which JLC uses to mark the PCB with a production number. The PCB design should comply with the tolerances of many more common (Chinese) PCB manufacturers, but this guide will only cover the JLCPCB ordering process.

The process starts by downloading the correct (usually latest) gerber zip package off the 2BitWizard GitHub. At the time of writing there are two options available, a normal model and a ”longboard” model. The longboard model contains a long neck on top of the PCB with a second connector on it. This PCB can be used to mount this project in a traditional GameBoy camera shell. This longboard model is designed to have its neck sawed off if or when you do decide to opt for a smaller cartridge.

After downloading the files they should not be unzipped. The zip file itself should instead be uploaded to the JLCPCB website. This will redirect you to the ordering screen. At this point you will be presented with a lot of options. Below is a large list of all the options and how they should be set. JLCPCBs ordering website may change over time, this list is only guaranteed to be complete at the time of writing, see table 1.

### 3 Ordering Parts

Now that the PCB has been ordered, it is time to select parts for your PCB. There are many suppliers available for all the different parts required. The viability of parts suppliers is highly dependent on your location. This part of the process might be tricky if your parts supplier does not provide you with a comprehensive filtering system. Common parts suppliers would be Mouser, Digikey and Farnell and AliExpress.

Start off by downloading the BOM.xlsx file from the GitHub. This file contains all the parts required for this project. Some of the parts on this BOM have specific parts names/numbers, other parts are more generic. It is recommended to buy matching part names/numbers as listed in the BOM. If these are not available you may try to find alternatives at your own risk by comparing datasheets of various other parts to the datasheet of the original part. Alternatively you could simply ask someone knowledgeable to do this for you.

To find these parts you can use the websites mentioned above to look for these parts, I personally used Mouser to source most of my parts. There are a few parts which are most easily acquired through AliExpress however. The flash memory chip is almost exclusively available on Aliexpress, the JST connector is easiest to find on AliExpress and the FRAM chip is cheapest on AliExpress. Generic components, like capacitors and resistors, may also be acquired through AliExpress

Table 1: An overview of JLCPCB options

Base Material | FR-4
Layers | 2
Dimensions | Auto-filled (leave be)
PCB Qty | As desired
Product type | Industrial/Consumer
| electronics
Different Design | 1
Delivery format | Single PCB
PCB thickness | 0.8
PCB Color | As desired
Silkscreen | As desired
Surface Finish | ENIG
Outer Copper weight | 1 oz
Via Covering | Tented
Board Outline Tolerance ±0.2mm(Regular)
Confirm Production file | No
Remove Order Number | Specify a location
Flying Probe Test | Fully Test
Gold Fingers | Yes
30°finger chamfered | No
Castellated Holes | No

at your own risk. If you’re not using AliExpress, but instead a website like Mouser, it’s easiest to make use of a filtering system. There are millions of capacitors and resistors out there. Most websites with a filtering system allow you to fill in certain parameters to narrow your search. It may help you out to filter by value, footprint and even an attribute like rating (X7R for the capacitors for example). Once you have found your parts, please double or even triple check that all values match the values listed in the BOM. Some parts may be available in multiple package options, in which case it is necessary to check that your part matches the footprint in the BOM. Finally it is recommended to buy enough parts to make mistakes during assembly. Buy more than you need, in case you break something.

It is important to note that the JST connector in the BOM is available in two options, a horizontal and a vertical version. It is recommended to buy a horizontal version. At the time of writing there are no custom shells available which make use of a vertically oriented connector.

### 4 Assembling the PCB

Assembling the PCB is where most people mess things up. This part requires the right tools and a considerable amount of skill. If you are not prepared to do your own soldering, contact someone within the community to do this for you. It is extremely easy to damage your valuable parts or the PCB. Assembling the PCB actually starts by disassembling the original GameBoy Camera PCB to harvest the MAC-GBD chip. This is most easily done with a hotplate set to roughly 230 celsius, it can however also be achieved with a heatgun or even chipquik, but these methods are inferior and not recommended.

Now to start the actual assembly process. It is recommended to use a high quality soldering iron with a fine tip of your choice and a high quality flux. While the parts may be placed on the

PCB in any order you like, there is an optimal part order for assembly when it comes to ease of soldering. Start off by solderint the MAC-GBD chip in the center of the board. This is followed by the flash chip and the SDRAM. Then follows the parts cluster on the top right of the PCB, values for each reference can be found in the BOM. Start off by soldering C15, C17, and U2. After this you may install U4 and C12. C16 is an optional capacitor, some alternate voltage regulators require this capacitor in their pinout, like the original GameBoy Camera regulator. The regulator specified in the BOM does not require a C16 capacitor to be mounted, in which case the pads may be left exposed. After finishing up the cluster of components in the top right you can solder all other components, saving J2 for last. J2, the connector which houses the sensor cable has a fairly complex footprint. This is because there are two available options for your connector. When using a vertical connector, solder its pins to the top row of pads (the pads closest to the PCB edge), when using a horizontal connector, solder its pins to the bottom row of pads. (the pads closest to the J2 silkscreen text), when using the longboard version of the PCB, leave the footprint on the main portion of the PCB alone and exclusively install a vertical JST connector on the extended part of the PCB.

After wrapping up the soldering process, plug in your PCB once more to verify that the RAM is at the very least detected. Detected RAM chips are still not guaranteed to work, so after this it is time to either flash the stock ROM or a custom ROM to the GameBoy Camera and boot it up with the sensor board attached. Observe the screen and check for any artifacting in camera mode. If the camera runs fine you’ve just made it. If it displays some sort of artifacting in the image you’re most likely dealing with a poor connection between the MAC-GBD and the FRAM chip/

### 5 Troubleshooting

If the camera is not working as intended there are a few easy things to check before seeking help from third parties online, like a Discord server. If your cart is not recognized at all when trying to flash a ROM, you will have to check each and every connection to verify that there are no shorts, floating pins or cold joints. If the cart detects the flash memory but has trouble writing to the actual flash memory, take a close look at the pins on the flash chip (left side of the board) and the left/bottom side pins of the MAC-GBD chip. If your camera does flash software and boots into the game and then suffers from artifacting in the camera image you’re most likely dealing with FRAM issues. Please closely inspect the pins on the FRAM chip (right side of the board) and the top/right side pins of the MAC-GBD.

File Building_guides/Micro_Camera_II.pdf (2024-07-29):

### GAMEBOY CAMERA CLUB

A DESIGN GUIDE BY 2BITWIZARD

# Design Guide

February 3, 2023
Version II.

### Contents

1 Introduction | 2
2 Reverse Engineering | 2
3 Selecting components | 2
4 PCB Design | 4
5 Conclusion | 5

### 1 Introduction

This document will cover all the design decisions made in the process of engineering this microcamera flashcart. It will cover the reverse engineering process, the part selection process and the PCB design process. This project was started to create an ultra-compact GameBoy Camera flashcart to fulfil various purposes. Some of its use cases are as follows:

- A compact version of the camera usable in the GameBoy Advance or other low-profile applications in other GameBoy models.
- A full size camera design with enough free space to mount another piece of hardware on the cartridge using a flex PCB.

### 2 Reverse Engineering

Reverse engineering started off with the following tools:

- Fluke 179 True RMS Multimeter
- BM-51-2 Stereo Microscope
- Amaran F1 LED panel

The original GameBoy Camera PCB was placed under the microscope and every single leg was probed and then promptly plotted out in a KiCad schematic file. This set up a basic net of connections between the components. The symbol pins were then named based on datasheet information where possible for the following components present on the GameBoy Camera:

- U3 - M5M51008BKV (Correct datasheet) [1]
- U2 - MX23C8004E-12 (datasheet from same family) [2]
- U1 - MAC-GBD (no datasheet available)
- J1 - M64282FP (Correct datasheet) [3]
- Cartridge edge connector [4]

While this covers most of the pins on these chips there are still some pins to figure out at this stage, mainly related to the circuitry present on the top right of the GameBoy Camera cartridge. This circuitry is related to the coin cell battery present on this PCB. After probing around for voltages and diodes it was determined that this circuitry uses the RST signal from the edge connector to regulate the standby mode of the SRAM chip. In detail this is done using an NPN mosfet and a dual BJT chip utilising a PNP and NPN BJT transistor, most likely to achieve the longest battery life possible. Above this piece of circuitry is one final piece of circuitry which mainly consists of a 3V0 voltage regulator and an electrolytic capacitor. Finally there are some stray components on the PCB which were easily figured out, by reading the silkscreen present on the PCB and occasionally using the multimeter for quick measurements. It has to be noted that the capacitors present on the original board have not been measured, instead the values of capacitors on the custom PCB are determined based on previous experience.

### 3 Selecting components

### 3.1 FRAM

To get rid of the battery present on the original GameBoy Camera a different type of RAM had to be used compared to the SRAM present on the original cart. This leaves three unique options to consider: FRAM, MRAM or NVRAM. The datasheet of the original SRAM dictated that I needed a RAM memory chip with 1MBit capacity arranged in a 128kx8 configuration. It also needs to run at a 3V supply rail. Finally it should match or beat the 120ns access time of the original chip. With these things in mind I filtered through all memory categories and came across three chips that could potentially work.

- FM28V100-TG (FRAM)
- CY14B101LA-SP25XIT (NVRAM)
- MR0A08BCMA35 (MRAM)

Unfortunately the MRAM option was out by default, because it was only offered in a BGA package. The NVRAM option looked compelling enough, it even being offered in an SSOP package. Unfortunately it lists its minimum voltage at 3V, which is pushing the boundaries a little too much. The FM28V100-TG FRAM was ultimately chosen, because it matched both the footprint and pinout of the original SRAM memory chip. This is a massive advantage over the other chips, because the MAC-GBD pinout appears to be designed with that exact SRAM pinout in mind. Finally while the FM28V100-TG does have a typical voltage rating of 3.3V, its datasheet mentions a minimum supply voltage of only 2.0V, which is firmly below the 3.0V present in my design.

### 3.2 Flash

To be able to make a flashcart, you do in fact need flash memory. Flash memory is a bit of a tricky one, because it has some other requirements beyond its technical compatibility with the MAC-GBD chip. The original ROM present on the cart is an 8Mbit chip arranged in a 1Mx8 configuration, running on a 5V0 input. Unfortunately there are no chips currently available for sale on Mouser that match these criteria. This meant I had to turn to the internet to find out which Flash chips were commonly used on flash cartridges for all kinds of systems, looking for chips that fit the bill. I ended up with a selection between two chips:

- AM29F080B
- AM29F016B

The AM29F080B has the exact amount of memory required to match the original ROM and also presents itself in the smaller footprint of the two. The first option would have allowed me to store two different ROMs on the flash cart, switching between them using a physical switch. This would have taken up too much space on my compact cart. As mentioned before, there are requirements beyond the technical compatibility with the MAC-GBD chip. It has to be easily flashable with readily available software when mounted on the cart. This is also the reason why the AM29F080B was chosen. It has seen previous use on flashcarts and therefore seems to be natively supported.

### 3.3 Other Components

Voltage Regulator The voltage Regulator has been replaced with a more modern LDO, which produces the same 3V0 output. The LDO with the best output has been chosen, though this is not strictly necessary. The electrolytic capacitor near the regulator has been replaced with a tantalum capacitor to minimize vertical obstruction within the game cart.

EMI filter The DC resistance of the ferrite beads present on the original cart has been measured. This has been used to select equivalent ferrite beads to solder onto the micro camera cart.

Diode The forward voltage of the diode D2 on the original cart was determined to hover around 215mV, so a similar schottky diode with a similar footprint has been selected to take its place.

This diode features a slightly lower voltage drop around 190mV, which should only benefit the circuitry.

Battery circuit The original battery circuit along with the battery has been removed and replaced with a single signal inverter. This takes the RST signal and outputs an inverted signal with an amplitude equal to the 3V0 supply used for this component. This should replicate the functionality of the original battery circuit putting the SRAM, or in this case FRAM, into a standby mode.

Capacitors All decoupling capacitors have somewhat arbitrarily been chosen to have a value of 10nF, except for one lone capacitor near the 5V0 pin of the edge connector. A single 100nF capacitor has been placed here as would be standard when decoupling circuitry.

Passives All passives have been changed to use an 0603 footprint. This makes the board more friendly to solder by hand.

### 4 PCB Design

To make this micro camera as compact as possible the routing of this PCB had to be as compact as possible. First off the MAC-GBD chip was placed as close to the bottom of the PCB as possible, restricted by two factors. The original cover for the GameBoy Camera has a plastic ridge which covers the connector pins. The decoupling capacitor still had to fit between this plastic ridge and the MAC-GBD chip. The address and data traces also still had to fit below the MAC-GBD chip with sufficient clearance. After this the MAC-GBD was shifted as far right as possible while still allowing the FRAM address lines to reach the MAC-GBD chip and wrap around a decoupling capacitor present inbetween the two chips.
Then the FRAM chip was placed, which was placed as close to the notch in the PCB as possible and as far right as possible. With these two chips in place the other address and data lines for the FRAM could be drawn. This would eventually determine the final height of the PCB as the sensor connector would still have to fit above these address and data lines.
The flash was placed evenly spaced between the notch on the left and the top of the PCB as far left as possible. This was done to allow as much space as possible between the decoupling capacitors and the flash chip.
With these major components in place all other components were placed inbetween with a similar layout as seen on the original camera PCB. After placing the main three components and routing a few traces to determine the height of the PCB all other traces were done. For concistency the address and datalines going towards the MAC-GBD chip were all placed on the front-side copper layer, with the data and address lanes splitting off to the flash memory being partially placed on the back-side copper layer. This only happened where necessary. This was done to ensure a large groundplane on the back of the PCB. The advantage of this large groundplane is that it minimizes hops through vias to ground each part of the PCB properly. Just like the original PCB a 5V0 loop was constructed on the back of the PCB, supplying power to all components that require it. While there is much more that went into the actual design of this PCB when it comes to the thousands of choices made when routing, the countless adjustments, zoning problems and general clearance headache, this should detail the main important decisions made when it comes to the unique design of this PCB. The last noteworthy thing is the footprint for the sensor’s JST connector. This footprint was created to support both a horizontal as well as vertical connector. The cart might not stick out of some GameBoys enough to mount a vertical camera connector, in which case a horizontal connector might have to be used.

### 5 Conclusion

This has been quite the adventure, to design an extremely compact GameBoy Camera flashcart. Reverse engineering was suprisingly simple. Finding components to make a flashcart was also taken care of rather quickly. I did however underestimate the amount of effort that would go into designing the PCB for this project. The PCB went through two major revisions. The first revision was scrapped after receiving some fair criticism. Instead of trying to resolve this criticism I decided to start over from scratch, believing I could do better than I did in this first revision. This lead to the second and current revision of this board. A prototype of the PCB is currently being produced as this is written and should be underway soon. The PCB successfully passes DRC and JLCPCB cleared the gerbers for production.

### References

[1] “M5M51008BKV Ram datasheet,” M5M51008BKV Datasheet | Mitsubishi - Datasheet-
spdf.com. [Online]. Available: https://datasheetspdf.com/datasheet/M5M51008BKV.html. [Accessed: 03-Feb-2023].
[2] Alldatasheet.com, “MX23C8000 datasheet,” ALLDATASHEET.COM - Electronic Parts Datasheet Search. [Online]. Available: https://pdf1.alldatasheet.com/datasheet-pdf/view/74426/MCNIX/MX23C8000.html. (https://pdf1.alldatasheet.com/datasheet-pdf/view/74426/MCNIX/MX23C8000.html) [Accessed: 03-Feb-2023].
[3] Alldatasheet.com, “M64282FP datasheet,” ALLDATASHEET.COM - Electronic Parts Datasheet Search. [Online]. Available: https://www.alldatasheet.com/datasheet-pdf/pdf/146598/MITSUBISHI/M64282FP.html. (https://www.alldatasheet.com/datasheet-pdf/pdf/146598/MITSUBISHI/M64282FP.html) [Accessed: 03-Feb-2023].
[4] M. Fayzullin, “Hardware,” GameBoy Hardware. [Online]. Available: https://fms.komkon.org/GameBoy/Tech/Hardware.html. (https://fms.komkon.org/GameBoy/Tech/Hardware.html) [Accessed: 03-Feb-2023].

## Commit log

2024-09-01 Proposal for an alternative BOM.md
2024-09-03 Validation of design with no voltage inverter and 10nf to 100nf
